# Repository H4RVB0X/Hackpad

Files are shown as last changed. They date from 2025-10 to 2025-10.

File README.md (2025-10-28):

# Macropad

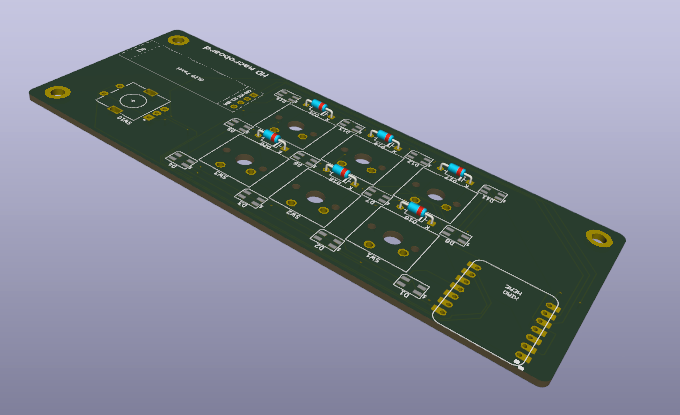
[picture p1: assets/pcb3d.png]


Macropad is a 6 key pad with a rotary encoder, an OLED display and 12 LED's. It uses KMK firmware.

It is inspired by the Hackpad YSWS (which has now ended so it is a now a hackpad blueprint)

## Features
- 3D printed custom case that is angled towards the user for easier use.
- 6 MX switches.
- 12 RGB LED's.
- A rotary encoder.
- A 128x32 OLED display.

## CAD Model for Case
It is screwed in using 3 M3 bolts and heatset inserts. It has a 10 degree tilt.

It is all one complete part with an open top to showcase the pcb and components.

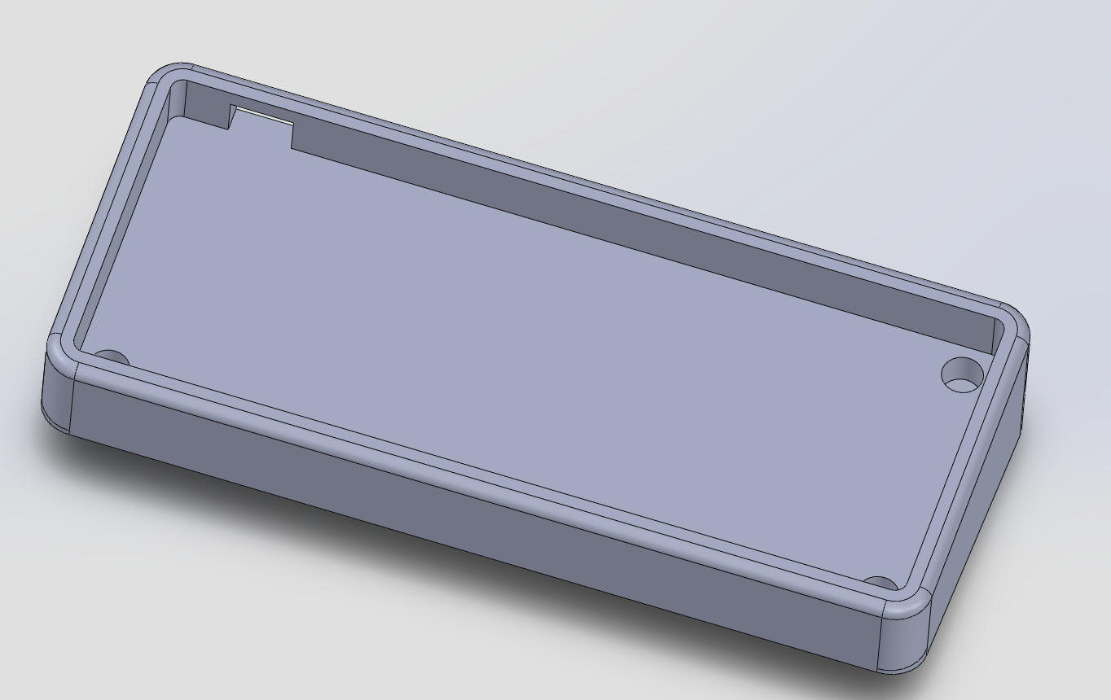
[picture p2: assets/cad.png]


Made in Solidworks.

## PCB
My PCB was designed in KiCad.

It was a challenge trying to route it all as I've never created a PCB before so ignore the messy wiring.

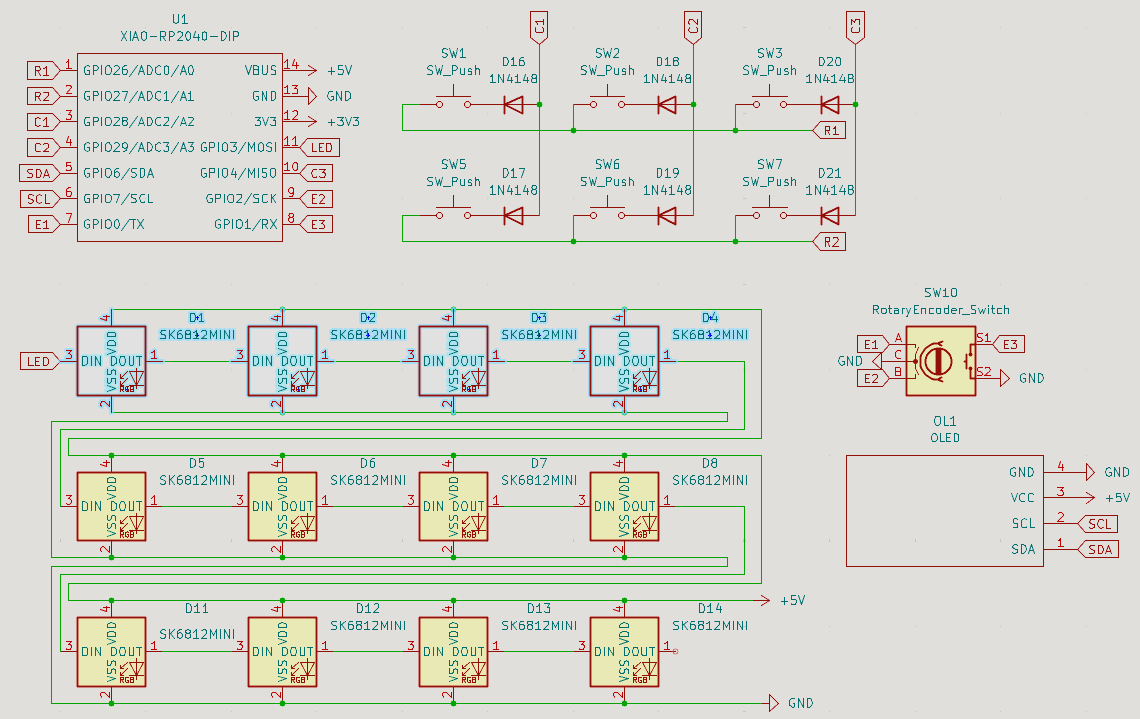
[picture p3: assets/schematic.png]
Schematic


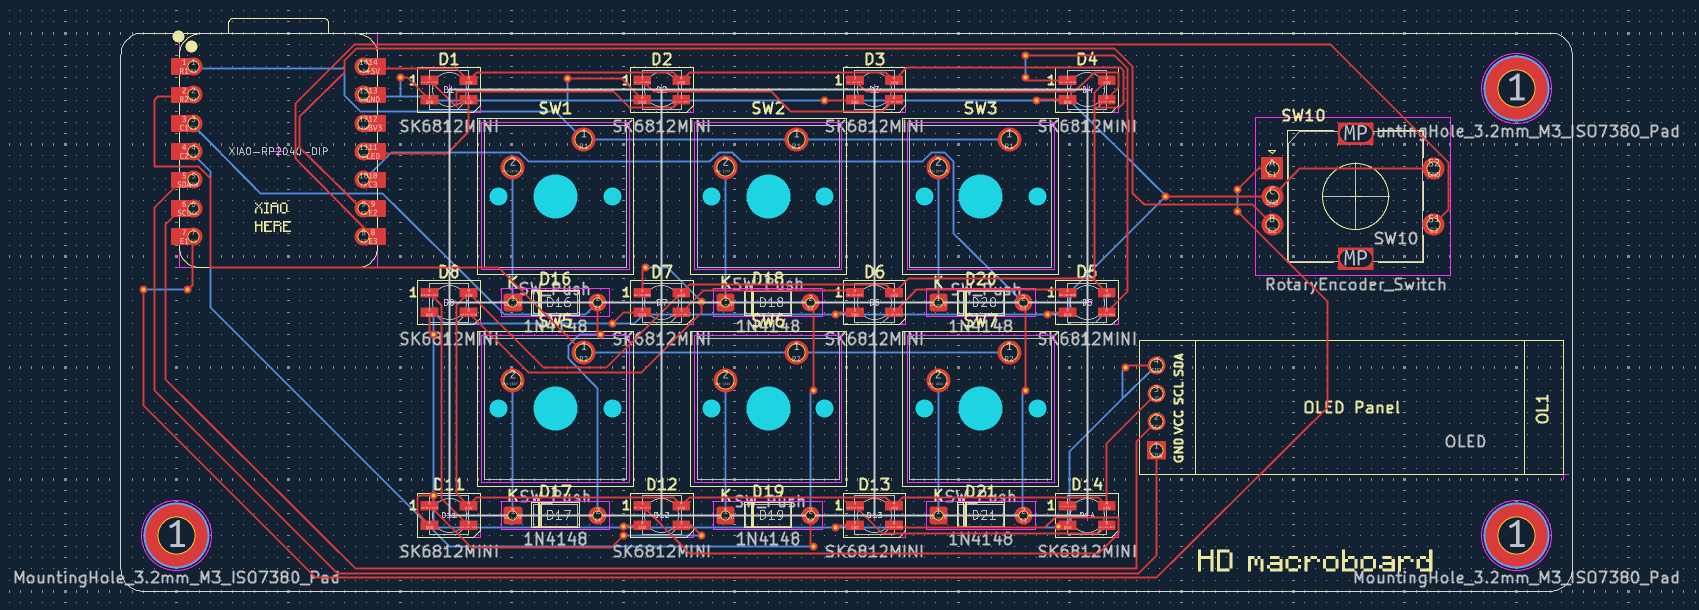
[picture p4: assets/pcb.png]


## Firmware Overview
It uses KMK firmware and may in the future be upgraded to QMK if I learn how to use it.

- The rotary encoder changes volume and is pressed to change layer.
- The 6 keys currently are assigned differently for each layer - Base (Gaming), Function, Media
- The OLED just tells you what layer your on and will in future have pictures or custom icons on there - maybe even temps if I can get that to work

## BOM

- 6x Cherry MX Switches
- 6x DSA Keycaps
- 3x M3x5x4 Heatset inserts
- 3x M3x16mm SHCS Bolts
- 6x 1N4148 DO-35 Diodes
- 12x WS2812B LEDs
- 1x 0.91" 128x32 OLED Display
- 1x EC11 Rotary Encoder
- 1x XIAO RP2040
- 1x Case (3D PrinteD)

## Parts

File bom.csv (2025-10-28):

Item | Description | Quantity | Unit price ($) | Total price ($) | URL | Running Total ($ with tax)
Seeed Studio XIAO RP2040 (Pre-Soldered) | MCU | 1 | $7.32 | $7.32 | https://www.aliexpress.com/item/1005007427287029.html | $7.32
1N4148 Small Signal Diode 100V 150mA | Diode | 1 | $1.01 | $1.01 | https://www.aliexpress.com/item/1005006245109375.html | $8.33
24 Pack of MX swithces | Switches | 1 | $1.01 | $1.01 | https://www.aliexpress.com/item/1005006255961111.html | $9.34
5 Pieces - Jadeshay Rotary Encoder Switch | Rotary encoder | 1 | $1.01 | $1.01 | https://www.aliexpress.com/item/1005005983134515.html | $10.35
MakerHawk 2 x I2C OLED Display Module I2C Screen Tiny Module 0.91 Inch White 128X32 | OLED screen | 1 | $1.01 | $1.01 | https://www.aliexpress.com/item/1005008640132638.html | $11.36
PATIKIL 1U Blank Keycaps | Keycaps | 1 | $4.30 | $4.30 | https://www.aliexpress.com/item/1005006302871892.html | $15.66
50PCS SK6812 MINI-E RGB | LED's | 1 | $1.01 | $1.01 | https://www.aliexpress.com/item/1005005340818659.html?mp=1 | $16.67
uxcell M3 x 16mm Hex Bolt Socket Head Cap Machine Screws Fasteners Black 100Pcs | Screws | 1 | $1.01 | $1.01 | https://www.aliexpress.com/item/32969042589.html | $17.68
HANGLIFE Threaded Inserts for Plastic | Threaded inserts | 1 | $1.63 | $1.63 | https://www.aliexpress.com/item/4000232858343.html?gatewayAdapt=usa2glo4itemAdapt | $19.31
PCB | PCB | 1 | $9.60 | $9.60 | https://trade.jlcpcb.com/ | $28.91

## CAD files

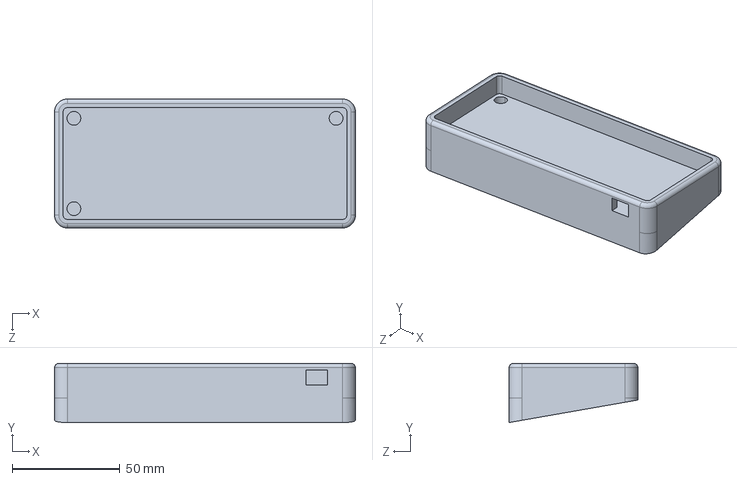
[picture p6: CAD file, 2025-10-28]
CAD/Main case.STEP
140.0 x 27.5 x 60.0 mm

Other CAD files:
CAD/Main case.SLDPRT

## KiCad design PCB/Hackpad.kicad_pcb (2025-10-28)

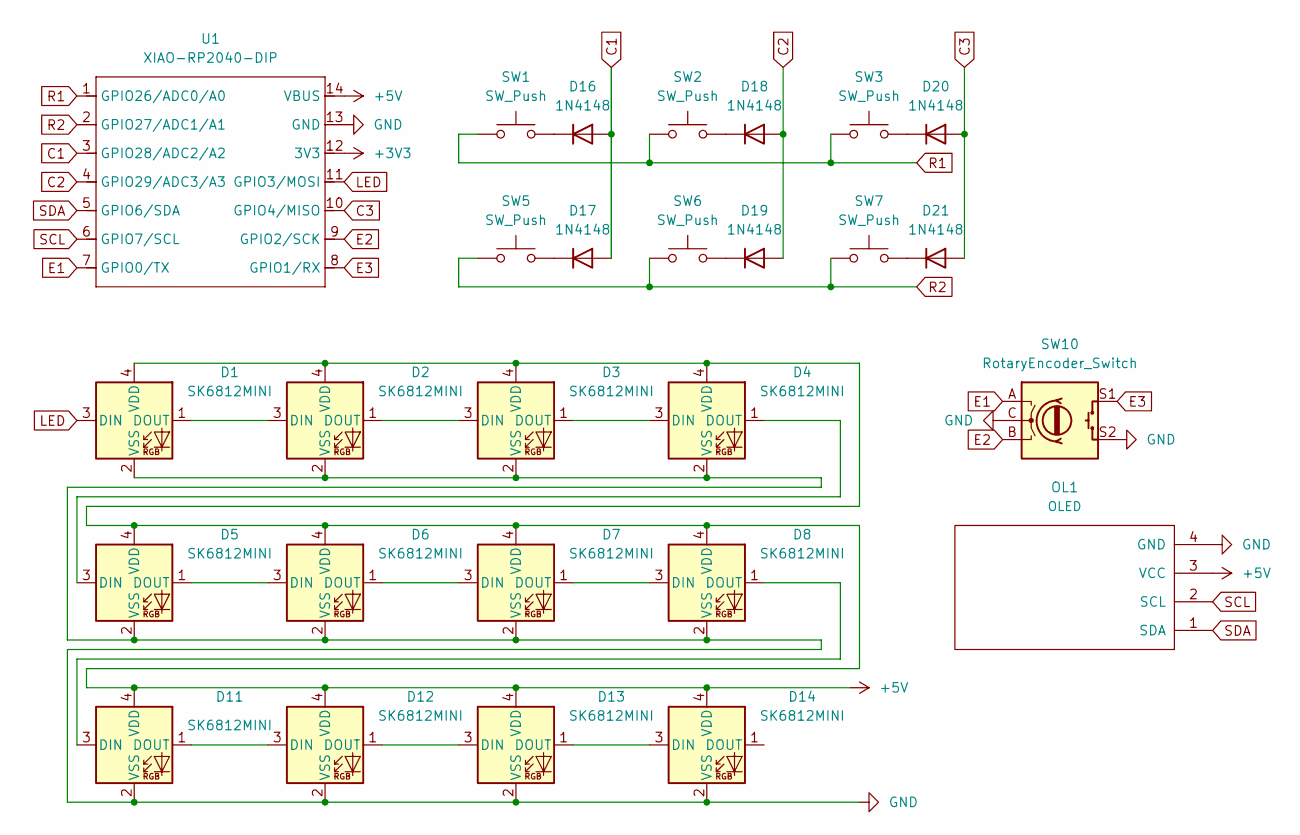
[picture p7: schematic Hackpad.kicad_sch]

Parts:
D1, D2, D3, D4, D5, D6, D7, D8, D11, D12, D13, D14: SK6812MINI; LED_SK6812MINI_PLCC4_3.5x3.5mm_P1.75mm
D16, D17, D18, D19, D20, D21: 1N4148; D_DO-35_SOD27_P7.62mm_Horizontal
OL1: OLED; SSD1306-0.91-OLED-4pin-128x32
SW1, SW2, SW3, SW5, SW6, SW7: SW_Push; SW_Cherry_MX_1.00u_PCB
SW10: RotaryEncoder_Switch; RotaryEncoder_Alps_EC11E-Switch_Vertical_H20mm
U1: XIAO-RP2040-DIP

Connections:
+3V3: U1.12 (3V3)
+5V: D1.4 (VDD), D2.4 (VDD), D3.4 (VDD), D4.4 (VDD), D5.4 (VDD), D6.4 (VDD), D7.4 (VDD), D8.4 (VDD), D11.4 (VDD), D12.4 (VDD), D13.4 (VDD), D14.4 (VDD), OL1.3 (VCC), U1.14 (VBUS)
C1: D16.2 (A), D17.2 (A), U1.3 (GPIO28/ADC2/A2)
C2: D18.2 (A), D19.2 (A), U1.4 (GPIO29/ADC3/A3)
C3: D20.2 (A), D21.2 (A), U1.10 (GPIO4/MISO)
E1: SW10.A, U1.7 (GPIO0/TX)
E2: SW10.B, U1.9 (GPIO2/SCK)
E3: SW10.S1, U1.8 (GPIO1/RX)
GND: D1.2 (VSS), D2.2 (VSS), D3.2 (VSS), D4.2 (VSS), D5.2 (VSS), D6.2 (VSS), D7.2 (VSS), D8.2 (VSS), D11.2 (VSS), D12.2 (VSS), D13.2 (VSS), D14.2 (VSS), OL1.4 (GND), SW10.C, SW10.S2, U1.13 (GND)
LED: D1.3 (DIN), U1.11 (GPIO3/MOSI)
unnamed: D1.1 (DOUT), D2.3 (DIN)
unnamed: D2.1 (DOUT), D3.3 (DIN)
unnamed: D3.1 (DOUT), D4.3 (DIN)
unnamed: D4.1 (DOUT), D5.3 (DIN)
unnamed: D5.1 (DOUT), D6.3 (DIN)
unnamed: D6.1 (DOUT), D7.3 (DIN)
unnamed: D7.1 (DOUT), D8.3 (DIN)
unnamed: D8.1 (DOUT), D11.3 (DIN)
unnamed: D11.1 (DOUT), D12.3 (DIN)
unnamed: D12.1 (DOUT), D13.3 (DIN)
unnamed: D13.1 (DOUT), D14.3 (DIN)
unnamed: D16.1 (K), SW1.2
unnamed: D17.1 (K), SW5.2
unnamed: D18.1 (K), SW2.2
unnamed: D19.1 (K), SW6.2
unnamed: D20.1 (K), SW3.2
unnamed: D21.1 (K), SW7.2
R1: SW1.1, SW2.1, SW3.1, U1.1 (GPIO26/ADC0/A0)
R2: SW5.1, SW6.1, SW7.1, U1.2 (GPIO27/ADC1/A1)
SCL: OL1.2 (SCL), U1.6 (GPIO7/SCL)
SDA: OL1.1 (SDA), U1.5 (GPIO6/SDA)

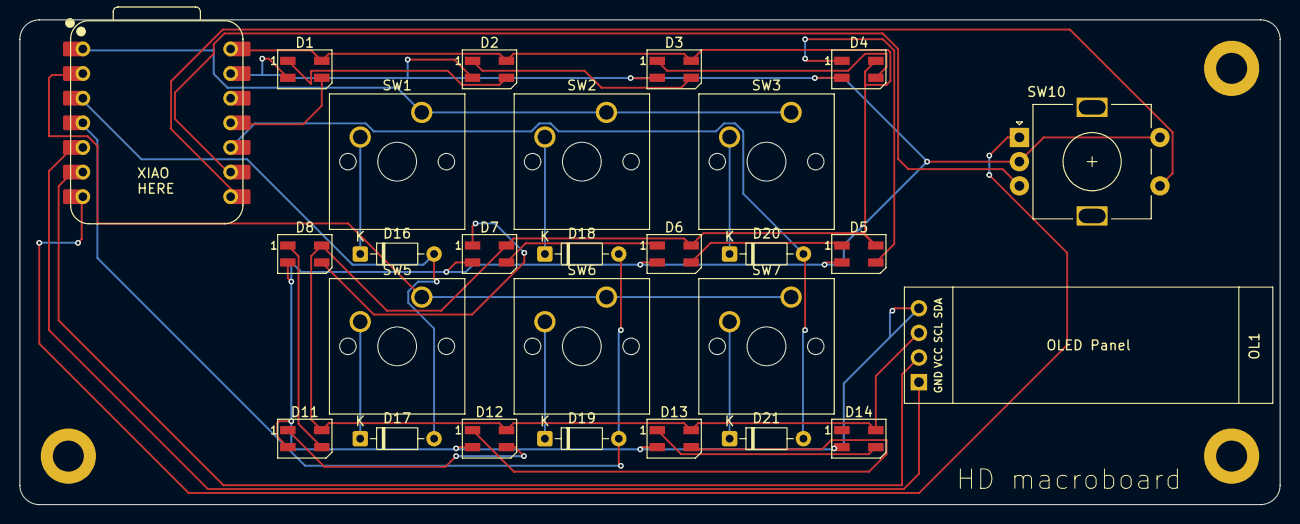
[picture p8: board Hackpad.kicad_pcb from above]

Board: 2 copper layers, 130.0 x 50.0 mm, 27 parts (0 on the bottom side), 30 nets.

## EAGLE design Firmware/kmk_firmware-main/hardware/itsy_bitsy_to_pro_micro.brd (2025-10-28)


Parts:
FRAME2: FRAME-LETTER; CREATIVE_COMMONS
JP1: HEADER-1X570MIL; 1X05_ROUND_70
JP2, JP4: HEADER-1X14; 1X14_ROUND70
JP3, JP5: M12PTH; 1X12

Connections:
!RESET: JP3.3, JP4.14
+3V3: JP4.13
A0: JP3.5, JP4.10
A1: JP3.6, JP4.9
A2: JP3.7, JP4.8
A3: JP3.8, JP4.7
A4: JP3.9, JP4.6
A5: JP3.10, JP4.5
AREF: JP4.12
D2: JP4.1
D3: JP1.4
D4: JP1.5
D5_5V: JP2.10
D7: JP2.9, JP5.1
D9: JP2.8, JP5.2
D10: JP2.7, JP5.3
D11: JP2.6, JP5.4
D12: JP2.5, JP5.5
D13: JP2.4, JP5.6
EN: JP1.1
GND: JP2.2, JP3.2, JP5.9, JP5.10
MISO: JP4.2
MOSI: JP3.12, JP4.3
RAW_PM: JP3.1
RX_D0: JP2.14, JP5.11
SCK: JP3.11, JP4.4
SCL: JP2.11, JP5.7
SDA: JP2.12, JP5.8
SWCLK: JP1.3
SWDIO: JP1.2
TX_D1: JP2.13, JP5.12
VBAT: JP2.1
VBUS: JP2.3, JP3.4
VHI: JP4.11

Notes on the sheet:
TX0/PD3->TX RX1/PD2->RX GND->GND GND->GND 2/PD1->SDA 3/PD0->SCL 4/PD4->13 5/PC6->12 6/PD7->11 7/PE6->10 8/PB4->9 9/PB5->7
OLD
Raw-> GND->GND RST->RST VCC->USB A3/PF4->A0 A2/PF5->A1 A1/PF6->A2 A0/PF7->A3 15/PB1->A4 14/PB3->A5 16/PB2->SCK 10/PB6->MOSI
Bryan Siepert



Board: 2 copper layers, 35.8 x 20.7 mm, 6 parts (2 on the bottom side), 21 nets.

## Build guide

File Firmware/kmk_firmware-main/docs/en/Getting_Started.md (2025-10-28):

# Getting Started
> Life was like a box of chocolates. You never know what you're gonna get.

KMK is a keyboard focused layer that sits on top of [CircuitPython](https://circuitpython.org/). As such, it should work with most [boards that support CircuitPython](https://circuitpython.org/downloads). KMK requires CircuitPython version 7.3 or above.
Known working and recommended devices can be found in the [list of officially supported microcontrollers](Officially_Supported_Microcontrollers.md)

## TL;DR Quick start guide
> To infinity and beyond!
1. [Install CircuitPython version 7.3 or higher on your board](https://learn.adafruit.com/welcome-to-circuitpython/installing-circuitpython). With most boards, it should be as easy as drag and dropping the firmware on the drive
2. Get an up to date [copy of KMK](https://github.com/KMKfw/kmk_firmware/archive/refs/heads/main.zip) from the main branch 
3. Unzip it and copy the KMK folder and the boot.py file at the root of the USB drive corresponding to your board (often appearing as CIRCUITPY)
4. Create a new *code.py* or *main.py* file in the same root directory (same level as boot.py) with the example content hereunder: 

***IMPORTANT:*** adapt the GP0 / GP1 pins to your specific board !

```
print("Starting")

import board

from kmk.kmk_keyboard import KMKKeyboard
from kmk.keys import KC
from kmk.scanners import DiodeOrientation

keyboard = KMKKeyboard()

keyboard.col_pins = (board.GP0,)
keyboard.row_pins = (board.GP1,)
keyboard.diode_orientation = DiodeOrientation.COL2ROW

keyboard.keymap = [
    [KC.A,]
]

if __name__ == '__main__':
    keyboard.go()
```

5. With a wire / paperclip / whatever, connect the pins you selected for col_pin and row_pin together.

feather and keeboar example pins


6. If it prints the letter "a" (or a "Q" or ... depending on your keyboard layout), you're done!

## Now that you're up and running, you may want to go further...
> This is your last chance. After this, there is no turning back. You take the blue pill—the story ends, you wake up in your bed and believe whatever you want to believe. You take the red pill—you stay in Wonderland, and I show you how deep the rabbit hole goes. Remember: all I'm offering is the truth. Nothing more.

### You're extremely lucky and you have a fully supported keyboard
If your keyboard and microcontroller are officially supported, simply visit the page for your files, and dropping them on the root of the "flash drive".
Those pages can be found in the repositories [boards folder](https://github.com/KMKfw/kmk_firmware/tree/master/boards).
You will need the `kb.py` and `main.py`. If you need more detailed instructions on how to customize the configuration settings and key mappings, please refer to the [config and keymap](config_and_keymap.md) documentation.

### You've got another, maybe DIY, board and want to customize KMK for it  
First, be sure to understand how your device work, and particularly its specific matrix configuration. You can have a look at [how key matrices work](http://pcbheaven.com/wikipages/How_Key_Matrices_Works/) or read the [guide](https://docs.qmk.fm/#/hand_wire) provided by the QMK team for handwired keyboards
Once you've got the gist of it:
- To start customizing your `code.py`/`main.py` file, please refer to the [config and keymap](config_and_keymap.md) and [keys](keys.md) files respectively, which provide detailed instructions on how to modify the configuration settings and key mappings.
- There's a [reference](keycodes.md) of the available keycodes
- [International](international.md) extension adds keys for non US layouts and [Media Keys](media_keys.md) adds keys for ... media

And to go even further:
- [Macros](macros.md) are used for sending multiple keystrokes in a single action
- [Layers](layers.md) can transform the whole way your keyboard is behaving with a single touch
- [HoldTap](holdtap.md) allow you to customize the way a key behaves whether it is tapped or hold, and [TapDance](tapdance.md) depending on the number of times it is pressed

Want to have fun features such as RGB, split keyboards and more? Check out what builtin [modules](modules.md) and [extensions](extensions.md) can do!
You can also get ideas from the various [user examples](https://github.com/KMKfw/kmk_firmware/tree/master/user_keymaps) that we provide and dig into our [documentation](README.md).

### Pre-compiling KMK for faster boot times or microcontrollers with limited flash

There are two options:
1. To compile KMK yourself you'll need to download and install the [compatible mpy-cross](https://adafruit-circuit-python.s3.amazonaws.com/index.html?prefix=bin/mpy-cross/)
  for your Operating System. Don't forget to add it to your PATH, test by running `mpy-cross` from a shell (Powershell, Bash, Fish, etc). Once that's set up, run either `make compile` (if you have `make`) or `python util/compile.py`to generate the `.mpy` versions of KMK files. Then copy the whole compiled `kmk/` directory to your keyboard.

There are even more compile and copy make targets.
Power user can compile KMK and additional libraries, and then load the bytecode and keyboard code
onto a keyboard in one go:
```sh
make compile copy-compiled copy-board MPY_SOURCES='kmk/ lib/' BOARD='boards/someboard' MOUNTPOINT='/media/user/someboard'
```

2. To download a pre-compiled KMK go to [Actions > Build on the KMK GitHub project page](https://github.com/KMKfw/kmk_firmware/actions/workflows/compile.yml),
  click on the latest build, and you'll find the download link at the bottom of the page under Artifacts. Unzip the download and place the contents in the `kmk/` directory on your keyboard.

On certain microcontrollers that will still not be enough of a size reduction to
fit all of KMK onto the flash (nice!nano for example).
You can remove any optional parts of KMK you aren't using.
Start by skipping `kmk/extensions`, `kmk/modules`, and `kmk/quickpin` and adding in only the files under those paths used in your keyboard (i.e. files that are imported in your `main.py` or `kb.py`).

## Additional help and support
> Roads? Where we're going we don't need roads.

In case you need it, debugging help can be found on the [debugging](debugging.md) page.

For asynchronous support and chatter about KMK, [join our Zulip
community](https://kmkfw.zulipchat.com)!

If you ask for help in chat or open a bug report, if possible
make sure your copy of KMK is up-to-date.
In particular, swing by the Zulip chat *before* opening a GitHub Issue about
configuration, documentation, etc. concerns.

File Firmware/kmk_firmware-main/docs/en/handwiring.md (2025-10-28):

# Handwire keyboards
This guide will not talk about the physical wiring. Check out our 
[recommended microcontrollers](Officially_Supported_Microcontrollers.md) and 
follow this amazing [hand wiring guide](https://docs.qmk.fm/#/hand_wire). That 
guide can be followed until you are setting up the firmware. After wiring the 
keyboard, you can refer to our [porting guide](porting_to_kmk.md)

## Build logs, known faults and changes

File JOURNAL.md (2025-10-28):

<!--
  ===================    !!READ THIS NOTICE!!   ====================
  DO NOT edit this file manually. Your changes WILL BE OVERWRITTEN!
  This journal is auto generated and updated by Hack Club Blueprint.
  To edit this file, please edit your journal entries on Blueprint.
  ==================================================================
-->

## 10/28/2025 2:33 PM - Made the schematic  



I designed the schematic for my macroboard. I first added all the parts I wanted then seperated them so that i can wire it easily. I used labels to decrease the amount of wires going from the sections of parts to the microcontroller. It was a challenge at first knowing what to wire to where but I eventually figured it all out. I first had more switches and 2 rotary encoders but quickly realised the microcontroller doesnt have enough room for everything so I changed it. For my first time usign KiCad im quite happy with my final result.  

## 10/28/2025 2:36 PM - Routed the PCB  



I then routed the PCB. This proved quite challenging to begin with as it was just a bunch of wires everywhere. I then slowly understood it and aligned my parts so that the wiring would be easier as they are all in order. I used a mix of front and back wires with viaducts so that it would all be able to fit. It took me 2 or 3 tries to fully get it right due to rearranging parts. The final result is a bit messy in wiring but it works for me.  

## 10/28/2025 2:39 PM - CAD  


Now, I needed to design the case for the macropad. This was quite easy as I have experience using solidworks. I just had to lay out the size of the pcb and add a 2mm allowance. I then added walls and then filleted them so it looks better and has less sharp edges. Then I added the holes for the screws. Next, I added the slot for the Type - C port of the the microcontroller. Finally I added the slant to the bottom. This didnt take me too long and has given me a simplistic open design case.

## 10/28/2025 2:45 PM - Firmware  


This part was challenging as I have never used KMK or any sort of keyboard firmware. I wanted to have 3 different layers so I have more options on what I can do with it. With some research I was slowly able to code it. I made the RGB a different colour for each layer and the OLED for now say what layer it is on. In the future I want to switch to QMK and maybe try getting temps to go on the OLED screen.

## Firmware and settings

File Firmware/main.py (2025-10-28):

from kmk.kmk_keyboard import KMKKeyboard
from kmk.keys import KC
from kmk.scanners.keypad import MatrixScanner
from kmk.modules.layers import Layers
from kmk.modules.encoder import EncoderHandler
from kmk.modules.oled import Oled, OledDisplayMode
from kmk.modules.rgb import RGB
import board
import time

keyboard = KMKKeyboard()

keyboard.row_pins = (board.GP26, board.GP27)
keyboard.col_pins = (board.GP28, board.GP29, board.GP4)
keyboard.diode_orientation = keyboard.DIODE_COL2ROW


layers = Layers()
encoder = EncoderHandler()
oled = Oled()
rgb = RGB(pixel_pin=board.GP3, num_pixels=12, hue_default=0)

keyboard.modules = [layers, encoder, oled, rgb]


oled.display_mode = OledDisplayMode.MANUAL 

LAYER_TEXTS = [
    "Layer 0: Base\nShortcuts & Typing",
    "Layer 1: Functions\nArrows & F-Keys",
    "Layer 2: Media\nPlayback & Volume",
]

def draw_oled(oled_obj, layer):
    oled_obj.clear()
    oled_obj.text(LAYER_TEXTS[layer], 0, 0)
    oled_obj.show()


encoder.pins = ((board.GP0, board.GP2, board.GP1),)

encoder.map = [
    ((KC.VOLD, KC.VOLU, KC.NO),),
]

last_encoder_button = False

def check_encoder_press():
    global last_encoder_button
    pressed = not keyboard.io.digital_read(board.GP1)
    if pressed and not last_encoder_button:
        new_layer = (keyboard.active_layers[0] + 1) % 3
        keyboard.activate_layer(new_layer)
        draw_oled(oled, new_layer)
    last_encoder_button = pressed


rgb.hue_step = 10
rgb.sat_step = 10
rgb.val_step = 10
rgb.animation_mode = None  

def rgb_layer_effect(layer):
    if layer == 0:
        rgb.set_hsv_fill(0, 255, 100)     # Red
    elif layer == 1:
        rgb.set_hsv_fill(85, 255, 100)    # Green
    elif layer == 2:
        rgb.set_hsv_fill(170, 255, 100)   # Blue

keyboard.after_layer_change = rgb_layer_effect


keyboard.keymap = [
    [  # Layer 0 - Base
        KC.Q, KC.W, KC.E,
        KC.A, KC.S, KC.D,
    ],
    [  # Layer 1 - Fn1
        KC.F1, KC.F2, KC.F3,
        KC.LEFT, KC.DOWN, KC.RIGHT,
    ],
    [  # Layer 2 - Media
        KC.MPRV, KC.MPLY, KC.MNXT,
        KC.VOLD, KC.VOLU, KC.MUTE,
    ],
]


def on_startup():
    rgb_layer_effect(0)
    draw_oled(oled, 0)

on_startup()


if __name__ == '__main__':
    while True:
        keyboard.tick()  
        check_encoder_press()
        time.sleep(0.01)

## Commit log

2025-10-28 Enhance README with features and technical details
    Expanded the README.md with detailed features, CAD model, PCB design, firmware overview, and BOM.
2025-10-28 firmware added
    [itsy_bitsy_to_pro_micro.brd, itsy_bitsy_to_pro_micro.sch, kmkpython_ref.tsv]
2025-10-28 Update and rename BOM - hackpad.csv to bom.csv
    [bom.csv]

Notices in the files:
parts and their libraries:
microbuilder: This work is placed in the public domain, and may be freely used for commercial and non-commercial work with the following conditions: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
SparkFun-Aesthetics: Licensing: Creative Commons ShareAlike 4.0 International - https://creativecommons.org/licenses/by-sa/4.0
